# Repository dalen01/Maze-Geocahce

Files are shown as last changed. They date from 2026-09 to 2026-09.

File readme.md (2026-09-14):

# Maze Geocache

An electronic maze puzzle inspired by the maze module in *Keep Talking and Nobody Explodes*. A player uses an arcade joystick to move a white light through an invisible maze on a 6×6 RGB LED matrix. Reaching four randomly selected goals in succession triggers a solenoid and opens the geocache.

This repository contains the Arduino firmware, KiCad PCB design and production files, enclosure models, and laser-cutting drawings required to build the project.

## How it works

- The two green LEDs identify which of the nine maze layouts is active.
- The white LED is the player's current position.
- The red LED is the goal.
- The joystick moves the player up, down, left, or right.
- Hitting a wall or the edge of the matrix displays a red cross and resets progress.
- Reaching a goal displays the number of rounds remaining and loads a new random maze.
- Completing four mazes plays a victory animation and energizes the solenoid for 500 ms.

The walls are intentionally not shown on the LED matrix. Players must use an external maze reference or solve the layout by deduction.

## Hardware

The supplied PCB is designed around the following main components:

- Arduino Nano or a pin-compatible board
- 36 × WS2812B addressable RGB LEDs arranged as a 6×6 matrix
- Arcade joystick with four directional switches
- Solenoid lock
- TIP120 Darlington transistor and SS34 flyback diode for solenoid control
- 3 × AA battery holder
- Custom PCB and enclosure

See [`PCB Design/Maze Geocache/production/bom.csv`](PCB%20Design/Maze%20Geocache/production/bom.csv) for the PCB bill of materials and component footprints.

## Pin assignment

| Function | Arduino Nano pin |
| --- | ---: |
| Solenoid control | D2 |
| Joystick up | D3 |
| Joystick down | D4 |
| Joystick right | D5 |
| Joystick left | D6 |
| WS2812B data | D7 |

The directional inputs use the Arduino's internal pull-up resistors and are active low.

## Firmware setup

### Requirements

- Arduino IDE or Arduino CLI
- Arduino AVR Boards package
- [Adafruit NeoPixel](https://github.com/adafruit/Adafruit_NeoPixel) library

### Prepare the sketch

The current sketch contains an absolute Windows path for `MazeWalls.h`. Before compiling on another computer:

1. Copy `Code/MazeWalls.h` into `Code/Maze/`.
2. Change the second line of `Code/Maze/Maze.ino` to:

```cpp
#include "MazeWalls.h"
```

### Upload with Arduino IDE

1. Open `Code/Maze/Maze.ino`.
2. Install **Adafruit NeoPixel** from the Library Manager.
3. Select **Arduino Nano** and the correct processor variant and serial port.
4. Compile and upload the sketch.
5. Optionally open the Serial Monitor at **9600 baud** to view movement and game-state messages.

## Assembly notes

1. Manufacture and populate the PCB from the files in `PCB Design/Maze Geocache/`.
2. Connect the four joystick switches to the matching UP, DOWN, LEFT, and RIGHT JST connectors.
3. Connect the solenoid to the two-pin screw terminal.
4. Install the Arduino Nano with the correct orientation.
5. Fit the PCB, joystick, lock, and battery holder into the enclosure.
6. Test all controls and the lock release before closing the enclosure.

The solenoid is an inductive, relatively high-current load. Do not drive it directly from an Arduino pin. Confirm the solenoid voltage, polarity, current requirement, transistor pinout, flyback-diode orientation, and power-source capability before applying power.

## Repository layout

| Path | Contents |
| --- | --- |
| `Code/` | Arduino sketch and maze wall definitions |
| `PCB Design/` | KiCad schematics, PCB layout, 3D board model, BOM, placement data, and fabrication archive |
| `3D Files/` | Fusion 360 archive and STEP model of the complete enclosure |
| `DXF Files/` | Laser-cutting drawings for the box and acrylic window |

## Customization

- Change `numberToGo` in `Maze.ino` to alter the number of successful mazes required to unlock the cache.
- Adjust the RGB values in `drawGame()` to change marker colors or brightness.
- Edit `circlePos`, `wallsVertical`, and `wallsHorizontal` in `MazeWalls.h` to change or add maze layouts. Update `MAZE_COUNT` when adding or removing layouts.
- Change the 500 ms delay in the victory sequence if the lock needs a different activation time, while staying within the solenoid's safe duty cycle.

## Fabrication warning

Review the PCB, mechanical files, clearances, power design, and production outputs before ordering parts or manufacturing. The repository does not include a verified electrical rating for the solenoid or batteries, and the design files should not be treated as production-ready without an independent check.

## Acknowledgements

The puzzle concept is inspired by the maze module from *Keep Talking and Nobody Explodes*. This is an independent fan project and is not affiliated with or endorsed by Steel Crate Games.

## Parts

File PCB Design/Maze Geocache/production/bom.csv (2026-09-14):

Designator | Footprint | Quantity | Value | LCSC Part #
A1 | Arduino_Nano | 1 | Arduino_Nano_v2.x
BT1 | BatteryHolder_TruPower_BH-331P_3xAA | 1 | Battery
C1, C10, C11, C12, C13, C14, C15, C16, C17, C18, C19, C2, C20, C21, C22, C23, C24, C25, C26, C27, C28, C29, C3, C30, C31, C32, C33, C34, C35, C36, C4, C5, C6, C7, C8, C9 | 1206 | 36 | 10pF
D1 | SS34 | 1 | SS34
D10, D11, D12, D13, D14, D15, D16, D17, D18, D19, D2, D20, D21, D22, D23, D24, D25, D26, D27, D28, D29, D3, D30, D31, D32, D33, D34, D35, D36, D37, D4, D5, D6, D7, D8, D9 | LED_WS2812B_PLCC4_5.0x5.0mm_P3.2mm | 36 | WS2812B
H1, H2, H3, H4 | MountingHole_2.5mm_Pad | 4 | MountingHole_Pad
J1 | JST_PH_B3B-PH-K_1x03_P2.00mm_Vertical | 1 | Joystick connector UP
J2 | JST_PH_B3B-PH-K_1x03_P2.00mm_Vertical | 1 | Joystick connector DOWN
J3 | JST_PH_B3B-PH-K_1x03_P2.00mm_Vertical | 1 | Joystick connector RIGHT
J4 | JST_PH_B3B-PH-K_1x03_P2.00mm_Vertical | 1 | Joystick connector LEFT
J5 | Altech_AK300_1x02_P5.00mm_45-Degree | 1 | Solenoid
Q1 | TO-220-3_Vertical | 1 | TIP120
R1 | 1206 | 1 | 220

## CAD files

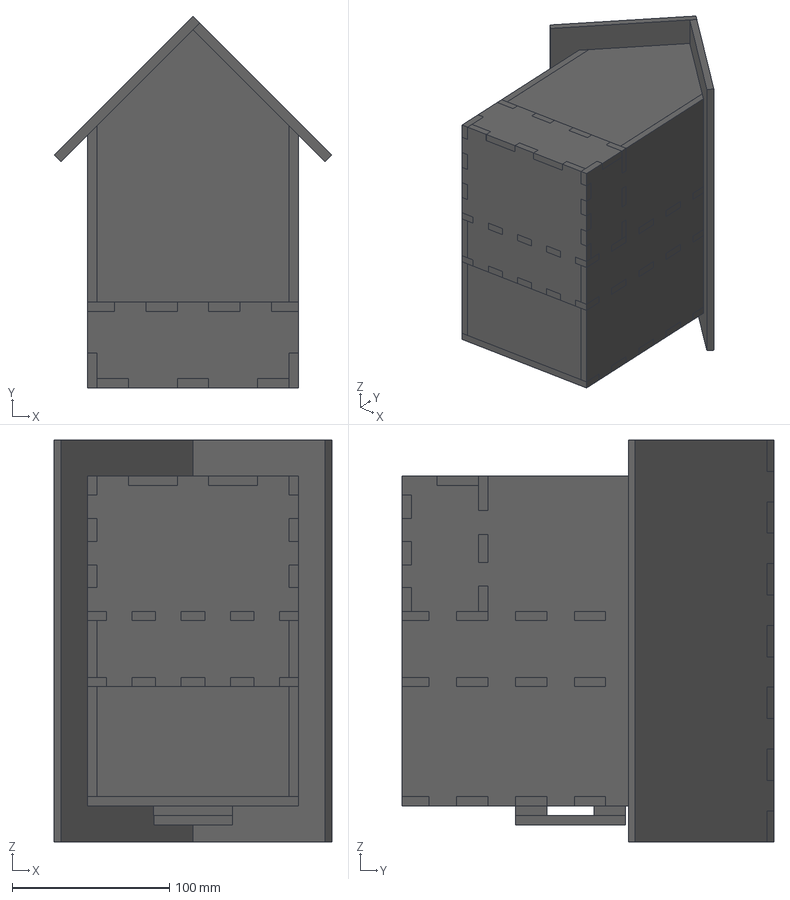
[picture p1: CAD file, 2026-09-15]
3D Files/Complete box with content 6mm.step
176.7 x 236.5 x 255.8 mm

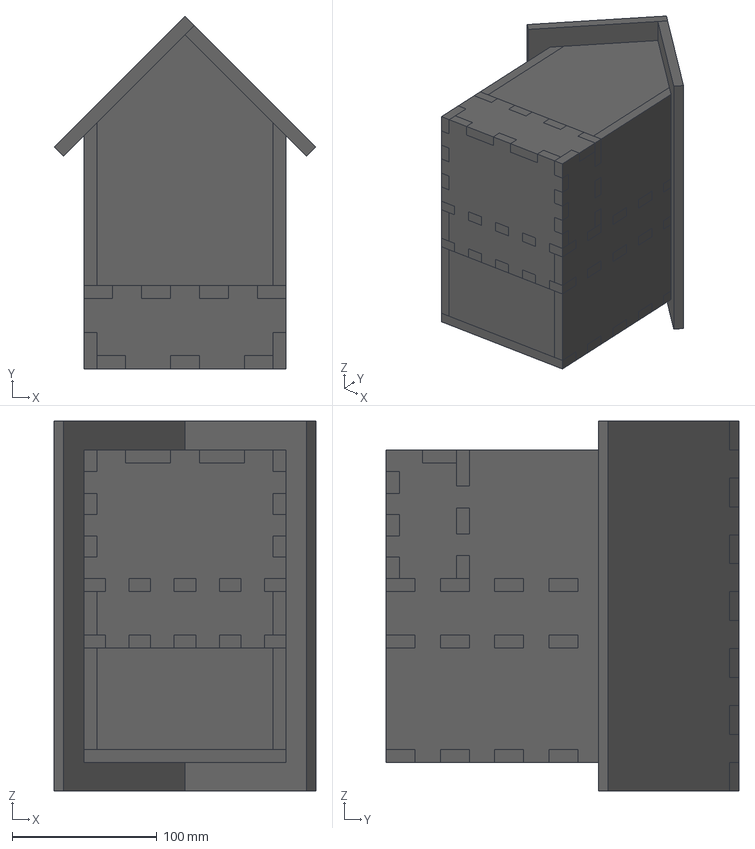
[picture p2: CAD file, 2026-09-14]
3D Files/Maze complete box with content.step
180.9 x 243.7 x 255.8 mm

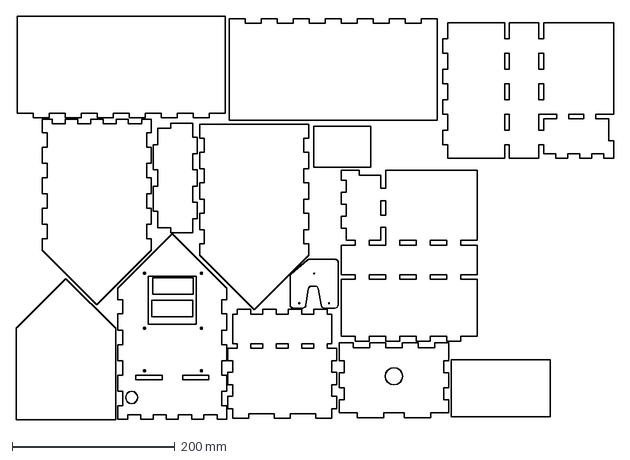
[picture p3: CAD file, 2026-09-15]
DXF Files/Box complete 6mm.dxf
733.9 x 495.8 mm

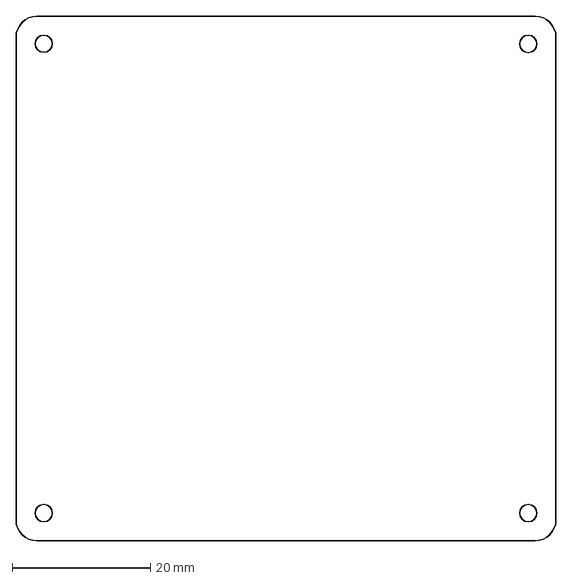
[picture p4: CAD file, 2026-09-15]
DXF Files/Acrylic 6mm.dxf
78.0 x 75.8 mm

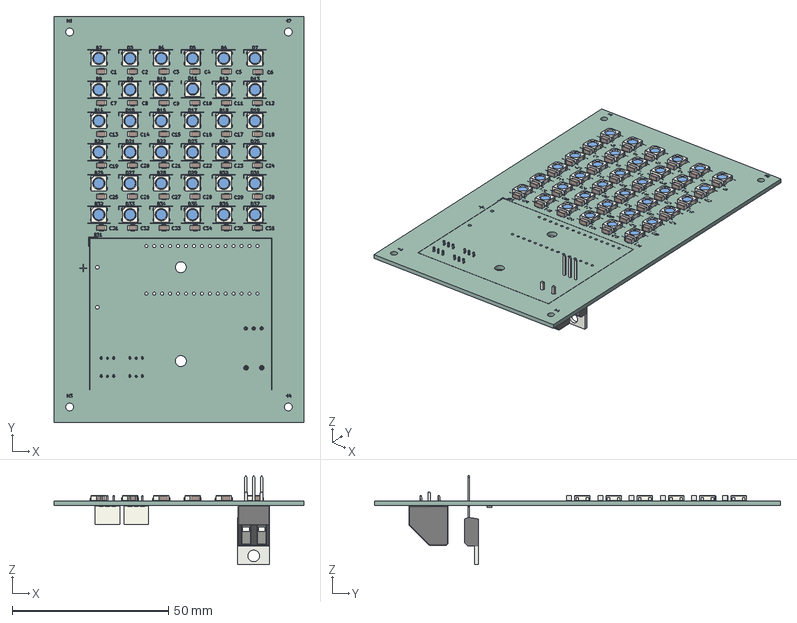
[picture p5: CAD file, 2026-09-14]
PCB Design/Maze Geocache/Maze Geocache.step
80.0 x 130.0 x 28.5 mm
C_1206_3216Metric x 36
LED_WS2812B_PLCC4_50x50mm_P32mm x 36
JST_B3B_PH_K x 4
R_1206_3216Metric
TO-220-3_Vertical
AK300_2
MasFFF3_silkscreen x 2
MasFFF3_PCB

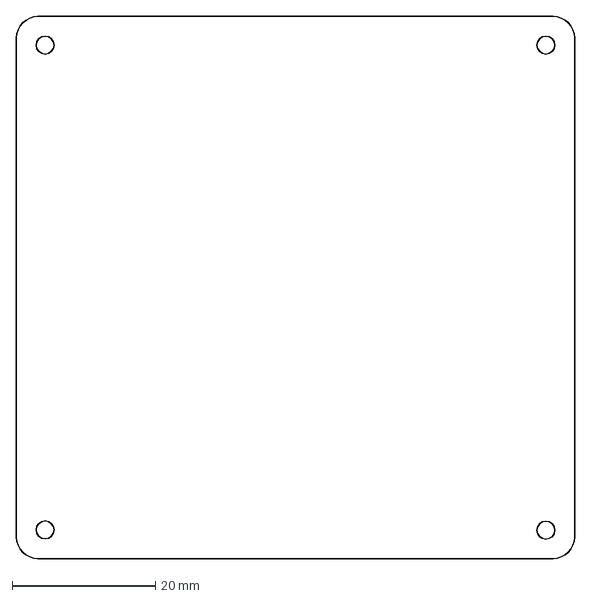
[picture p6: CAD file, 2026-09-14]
DXF Files/Acryl glass.dxf
78.0 x 75.8 mm

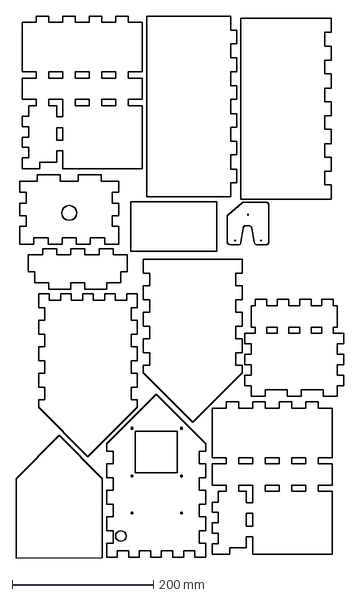
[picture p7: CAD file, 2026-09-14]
DXF Files/Box ready.dxf
463.5 x 767.5 mm

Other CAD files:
3D Files/Maze Geocache Fusion Archive 6mm.f3d
3D Files/Maze Geocache Fusion Archive.f3d

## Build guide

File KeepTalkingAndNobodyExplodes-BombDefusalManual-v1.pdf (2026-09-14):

8/28/2020 | KeepTalkingandNobodyExplodes-BombDefusalManual-en-v1

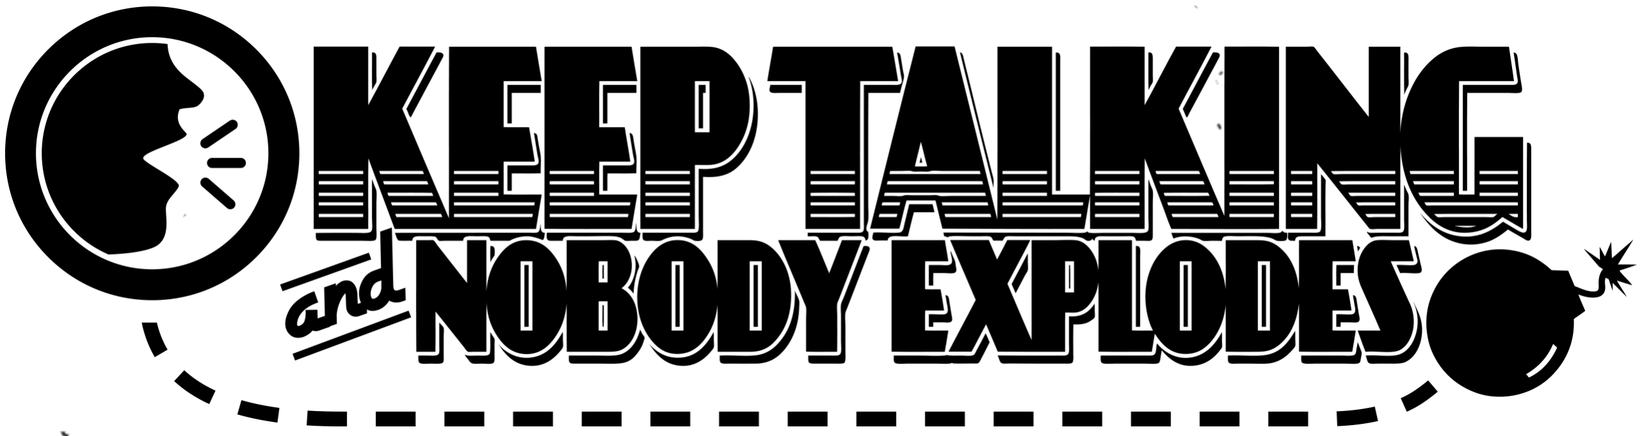
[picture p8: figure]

file:///C:/SteelCrate/KTaNE/git/Manual/build/en/print/source_html/index.html | 1/23

# BOMB DEFUSAL MANUAL

# www.keeptalkinggame.com

# Version 1 Verification Code: 241

Video game companion manual. Find out more at www.keeptalkinggame.com

file:///C:/SteelCrate/KTaNE/git/Manual/build/en/print/source_html/index.html | 2/23

Welcome to the dangerous and challenging world of bomb defusing.

Study this manual carefully; you are the expert. In these pages you will find everything you need to know to defuse even the most insidious of bombs. And remember — One small oversight and it could all be over!

Keep Talking and Nobody Explodes v. 1 | Introduction

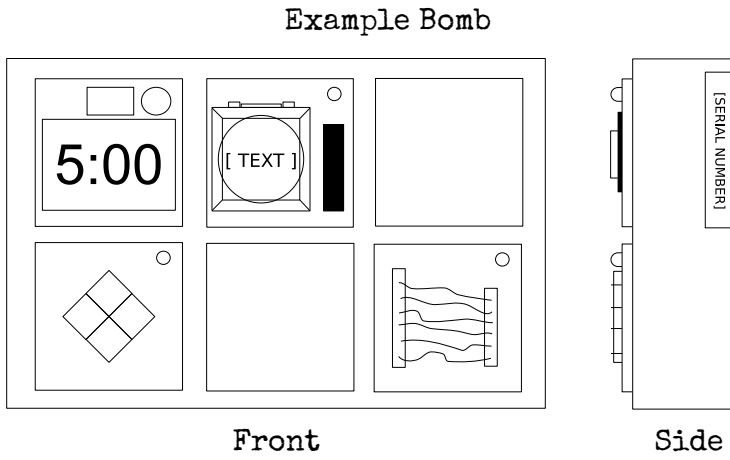
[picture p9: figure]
Example Bomb; Front; Side

file:///C:/SteelCrate/KTaNE/git/Manual/build/en/print/source_html/index.html | 3/23

Strike
Indicator

# Defusing Bombs

A bomb will explode when its countdown timer reaches 0:00 or when too many strikes have been recorded. The only way to defuse a bomb is to disarm all of its modules before its countdown timer expires.

Modules

Each bomb will include up to 11 modules that must be disarmed. Each module is discrete and can be disarmed in any order.

Instructions for disarming modules can be found in Section 1. "Needy" modules present a special case and are described in Section 2.

Strikes

When the Defuser makes a mistake, the bomb will record a strike which will be displayed on the indicator above the countdown timer. Bombs with a strike indicator will explode upon the third strike. The timer will begin to count down faster after a strike has been recorded.

If no strike indicator is present above the countdown timer, the bomb will explode upon the first strike, leaving no room for error.

Gathering Information

Some disarming instructions will require specific information about the bomb, such as the serial number. This type of information can typically be found on the top, bottom, or sides of the bomb casing. See Appendix A, B, and C for identification instructions that will be useful in disarming certain modules.

Keep Talking and Nobody Explodes v. 1 | Defusing Bombs

file:///C:/SteelCrate/KTaNE/git/Manual/build/en/print/source_html/index.html | 4/23

# Section 1: Modules

Modules can be identified by an LED in the top right corner. When this LED is lit green, the module has been disarmed.

All modules must be disarmed to defuse the bomb.

Keep Talking and Nobody Explodes v. 1 | Section 1: Modules

file:///C:/SteelCrate/KTaNE/git/Manual/build/en/print/source_html/index.html | 5/23

## On the Subject of Wires

Wires are the lifeblood of electronics! Wait, no, electricity is the lifeblood. Wires are more like the arteries. The veins? No matter…

A wire module can have 3-6 wires on it.
Only the one correct wire needs to be cut to disarm the module.
Wire ordering begins with the first on the top.

3 wires:
If there are no red wires, cut the second wire.
Otherwise, if the last wire is white, cut the last wire.
Otherwise, if there is more than one blue wire, cut the last blue wire. Otherwise, cut the last wire.

4 wires:
If there is more than one red wire and the last digit of the serial number is odd, cut the last red wire.
Otherwise, if the last wire is yellow and there are no red wires, cut the first wire.
Otherwise, if there is exactly one blue wire, cut the first wire.
Otherwise, if there is more than one yellow wire, cut the last wire. Otherwise, cut the second wire.

5 wires:
If the last wire is black and the last digit of the serial number is odd, cut the fourth wire.
Otherwise, if there is exactly one red wire and there is more than one yellow wire, cut the first wire.
Otherwise, if there are no black wires, cut the second wire.
Otherwise, cut the first wire.

6 wires:
If there are no yellow wires and the last digit of the serial number is odd, cut the third wire.
Otherwise, if there is exactly one yellow wire and there is more than one white wire, cut the fourth wire.
Otherwise, if there are no red wires, cut the last wire.
Otherwise, cut the fourth wire.
Keep Talking and Nobody Explodes v. 1 | Wires

file:///C:/SteelCrate/KTaNE/git/Manual/build/en/print/source_html/index.html | 6/23

## On the Subject of The Button

You might think that a button telling you to press it is pretty straightforward. That’s the kind of thinking that gets people exploded.

See Appendix A for indicator identification reference. See Appendix B for battery identification reference.

Follow these rules in the order they are listed. Perform the
first action that applies:
1. If the button is blue and the button says "Abort", hold the button and refer to "Releasing a Held Button".
2. If there is more than 1 battery on the bomb and the button says "Detonate", press and immediately release the button.
3. If the button is white and there is a lit indicator with label CAR, hold the button and refer to "Releasing a Held Button".
4. If there are more than 2 batteries on the bomb and there is a lit indicator with label FRK, press and immediately release the button.
5. If the button is yellow, hold the button and refer to "Releasing a Held Button".
6. If the button is red and the button says "Hold", press and immediately release the button.
7. If none of the above apply, hold the button and refer to "Releasing a Held Button".

Releasing a Held Button

If you start holding the button down, a colored strip will light up on the right side of the module. Based on its color, you must release the button at a specific point in time:

Blue strip: release when the countdown timer has a 4 in any position. White strip: release when the countdown timer has a 1 in any position. Yellow strip: release when the countdown timer has a 5 in any position. Any other color strip: release when the countdown timer has a 1 in any position.

Keep Talking and Nobody Explodes v. 1 | The Button

file:///C:/SteelCrate/KTaNE/git/Manual/build/en/print/source_html/index.html | 7/23

## On the Subject of Keypads

I'm not sure what these symbols are, but I suspect they have something to do with occult.

Only one column below has all four of the symbols from the keypad.
Press the four buttons in the order their symbols appear from top to bottom within that column.
Keep Talking and Nobody Explodes v. 1 | Keypads

file:///C:/SteelCrate/KTaNE/git/Manual/build/en/print/source_html/index.html | 8/23

## On the Subject of Simon Says

This is like one of those toys you played with as a kid where you have to match the pattern that appears, except this one is a knockoff that was probably purchased at a dollar store.

1. One of the four colored buttons will flash.
2. Using the correct table below, press the button with the
corresponding color.
3. The original button will flash, followed by another. Repeat this sequence in order using the color mapping.
4. The sequence will lengthen by one each time you correctly enter a sequence until the module is disarmed.

## Blue

Red | Yellow

## Green

If the serial number contains a vowel:

Red Flash | Blue Flash | Green Flash | Yellow Flash
Button to press: | No Strikes | Blue | Red | Yellow | Green
| 1 Strike | Yellow | Green | Blue | Red
| 2 Strikes | Green | Red | Yellow | Blue

If the serial number does not contain a vowel:

Red Flash | Blue Flash | Green Flash | Yellow Flash
Button to press: | No Strikes | Blue | Yellow | Green | Red
| 1 Strike | Red | Blue | Yellow | Green
| 2 Strikes | Yellow | Green | Blue | Red
Keep Talking and Nobody Explodes v. 1 | Simon Says

file:///C:/SteelCrate/KTaNE/git/Manual/build/en/print/source_html/index.html | 9/23

## On the Subject of Who’s on First

This contraption is like something out of a sketch comedy routine, which might be funny if it wasn't connected to a bomb. I’ll keep this brief, as words only complicate matters.

1. Read the display and use step 1 to determine which button label to read.
2. Using this button label, use step 2 determine which button to push.
3. Repeat until the module has been disarmed.
Step 1:

Based on the display, read the label of a particular button and proceed to step 2:

YES | FIRST | DISPLAY | OKAY | SAYS | NOTHING
BLANK | NO | LED | LEAD | READ
RED | REED | LEED | HOLD ON | YOU | YOU ARE
YOUR | YOU'RE | UR | THERE | THEY'RE | THEIR
THEY ARE | SEE | C | CEE
Keep Talking and Nobody Explodes v. 1 | Who's on First

file:///C:/SteelCrate/KTaNE/git/Manual/build/en/print/source_html/index.html | 10/23
Step 2:

Using the label from step 1, push the first button that appears in its corresponding list:

"READY": | YES, OKAY, WHAT, MIDDLE, LEFT, PRESS, RIGHT, BLANK, READY, NO, FIRST, UHHH, NOTHING, WAIT
"FIRST": | LEFT, OKAY, YES, MIDDLE, NO, RIGHT, NOTHING, UHHH, WAIT, READY, BLANK, WHAT, PRESS, FIRST
"NO": | BLANK, UHHH, WAIT, FIRST, WHAT, READY, RIGHT, YES, NOTHING, LEFT, PRESS, OKAY, NO, MIDDLE
"BLANK": | WAIT, RIGHT, OKAY, MIDDLE, BLANK, PRESS, READY, NOTHING, NO, WHAT, LEFT, UHHH, YES, FIRST
"NOTHING": | UHHH, RIGHT, OKAY, MIDDLE, YES, BLANK, NO, PRESS, LEFT, WHAT, WAIT, FIRST, NOTHING, READY
"YES": | OKAY, RIGHT, UHHH, MIDDLE, FIRST, WHAT, PRESS, READY, NOTHING, YES, LEFT, BLANK, NO, WAIT
"WHAT": | UHHH, WHAT, LEFT, NOTHING, READY, BLANK, MIDDLE, NO, OKAY, FIRST, WAIT, YES, PRESS, RIGHT
"UHHH": | READY, NOTHING, LEFT, WHAT, OKAY, YES, RIGHT, NO, PRESS, BLANK, UHHH, MIDDLE, WAIT, FIRST
"LEFT": | RIGHT, LEFT, FIRST, NO, MIDDLE, YES, BLANK, WHAT, UHHH, WAIT, PRESS, READY, OKAY, NOTHING
"RIGHT": | YES, NOTHING, READY, PRESS, NO, WAIT, WHAT, RIGHT, MIDDLE, LEFT, UHHH, BLANK, OKAY, FIRST
"MIDDLE": | BLANK, READY, OKAY, WHAT, NOTHING, PRESS, NO, WAIT, LEFT, MIDDLE, RIGHT, FIRST, UHHH, YES
"OKAY": | MIDDLE, NO, FIRST, YES, UHHH, NOTHING, WAIT, OKAY, LEFT, READY, BLANK, PRESS, WHAT, RIGHT
"WAIT": | UHHH, NO, BLANK, OKAY, YES, LEFT, FIRST, PRESS, WHAT, WAIT, NOTHING, READY, RIGHT, MIDDLE
"PRESS": | RIGHT, MIDDLE, YES, READY, PRESS, OKAY, NOTHING, UHHH, BLANK, LEFT, FIRST, WHAT, NO, WAIT
"YOU": | SURE, YOU ARE, YOUR, YOU'RE, NEXT, UH HUH, UR, HOLD, WHAT?, YOU, UH UH, LIKE, DONE, U
"YOU ARE": | YOUR, NEXT, LIKE, UH HUH, WHAT?, DONE, UH UH, HOLD, YOU, U, YOU'RE, SURE, UR, YOU ARE
"YOUR": | UH UH, YOU ARE, UH HUH, YOUR, NEXT, UR, SURE, U, YOU'RE, YOU, WHAT?, HOLD, LIKE, DONE
"YOU'RE": | YOU, YOU'RE, UR, NEXT, UH UH, YOU ARE, U, YOUR, WHAT?, UH HUH, SURE, DONE, LIKE, HOLD
"UR": | DONE, U, UR, UH HUH, WHAT?, SURE, YOUR, HOLD, YOU'RE, LIKE, NEXT, UH UH, YOU ARE, YOU
"U": | UH HUH, SURE, NEXT, WHAT?, YOU'RE, UR, UH UH, DONE, U, YOU, LIKE, HOLD, YOU ARE, YOUR
"UH HUH": | UH HUH, YOUR, YOU ARE, YOU, DONE, HOLD, UH UH, NEXT, SURE, LIKE, YOU'RE, UR, U, WHAT?
"UH UH": | UR, U, YOU ARE, YOU'RE, NEXT, UH UH, DONE, YOU, UH HUH, LIKE, YOUR, SURE, HOLD, WHAT?
"WHAT?": | YOU, HOLD, YOU'RE, YOUR, U, DONE, UH UH, LIKE, YOU ARE, UH HUH, UR, NEXT, WHAT?, SURE
"DONE": | SURE, UH HUH, NEXT, WHAT?, YOUR, UR, YOU'RE, HOLD, LIKE, YOU, U, YOU ARE, UH UH, DONE
"NEXT": | WHAT?, UH HUH, UH UH, YOUR, HOLD, SURE, NEXT, LIKE, DONE, YOU ARE, UR, YOU'RE, U, YOU
"HOLD": | YOU ARE, U, DONE, UH UH, YOU, UR, SURE, WHAT?, YOU'RE, NEXT, HOLD, UH HUH, YOUR, LIKE
"SURE": | YOU ARE, DONE, LIKE, YOU'RE, YOU, HOLD, UH HUH, UR, SURE, U, WHAT?, NEXT, YOUR, UH UH
"LIKE": | YOU'RE, NEXT, U, UR, HOLD, DONE, UH UH, WHAT?, UH HUH, YOU, LIKE, SURE, YOU ARE, YOUR
Keep Talking and Nobody Explodes v. 1 | Who's on First

file:///C:/SteelCrate/KTaNE/git/Manual/build/en/print/source_html/index.html | 11/23

## On the Subject of Memory

Memory is a fragile thing but so is everything else when a bomb goes off, so pay attention!

Press the correct button to progress the module to the next stage. Complete all stages to disarm the module. Pressing an incorrect button will reset the module back to stage 1.
Button positions are ordered from left to right.

Stage 1:
If the display is 1, press the button in the second position. If the display is 2, press the button in the second position. If the display is 3, press the button in the third position. If the display is 4, press the button in the fourth position.

Stage 2:
If the display is 1, press the button labeled "4".
If the display is 2, press the button in the same position as you pressed in stage 1. If the display is 3, press the button in the first position.
If the display is 4, press the button in the same position as you pressed in stage 1.

Stage 3:
If the display is 1, press the button with the same label you pressed in stage 2.
If the display is 2, press the button with the same label you pressed in stage 1. If the display is 3, press the button in the third position.
If the display is 4, press the button labeled "4".

Stage 4:
If the display is 1, press the button in the same position as you pressed in stage 1. If the display is 2, press the button in the first position.
If the display is 3, press the button in the same position as you pressed in stage 2. If the display is 4, press the button in the same position as you pressed in stage 2.

Stage 5:
If the display is 1, press the button with the same label you pressed in stage 1.
If the display is 2, press the button with the same label you pressed in stage 2. If the display is 3, press the button with the same label you pressed in stage 4. If the display is 4, press the button with the same label you pressed in stage 3.
Keep Talking and Nobody Explodes v. 1 | Memory

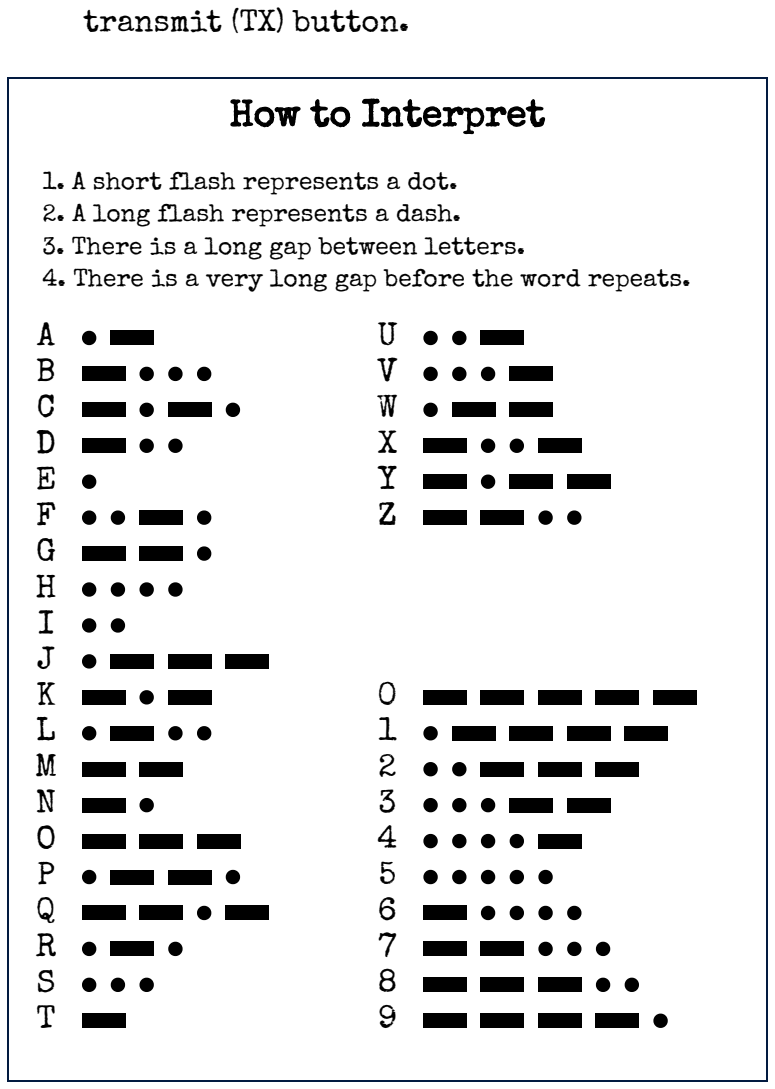
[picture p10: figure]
How to Interpret; 1. A short flash represents a dot. 2. A long flash represents a dash. 3. There is a long gap between letters.; transmit (TX) button.

file:///C:/SteelCrate/KTaNE/git/Manual/build/en/print/source_html/index.html | 12/23
4. There is a very long gap before the word repeats.

## On the Subject of Morse Code

An antiquated form of naval communication? What next? At least it's genuine Morse Code, so pay attention and you might just learn something.

Interpret the signal from the flashing light using the Morse Code chart to spell one of the words in the table.
The signal will loop, with a long gap between
repetitions.
Once the word is identified, set the corresponding frequency and press the
If the word is: | Respond at frequency:
shell | 3.505 MHz
halls | 3.515 MHz
slick | 3.522 MHz
trick | 3.532 MHz
boxes | 3.535 MHz
leaks | 3.542 MHz
strobe | 3.545 MHz
bistro | 3.552 MHz
flick | 3.555 MHz
bombs | 3.565 MHz
break | 3.572 MHz
brick | 3.575 MHz
steak | 3.582 MHz
sting | 3.592 MHz
vector | 3.595 MHz
beats | 3.600 MHz
Keep Talking and Nobody Explodes v. 1 | Morse Code

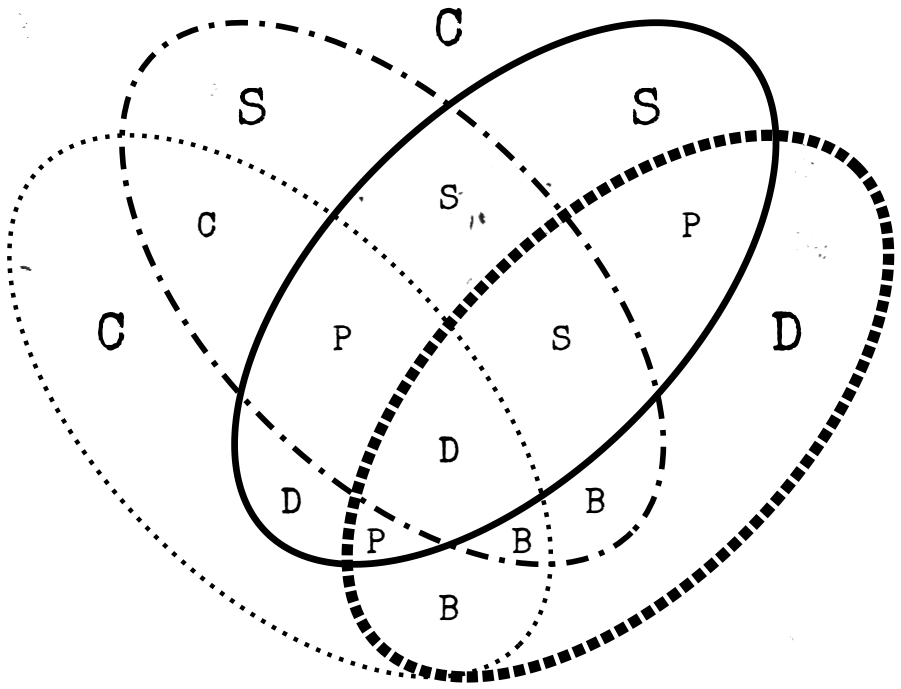
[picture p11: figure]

file:///C:/SteelCrate/KTaNE/git/Manual/build/en/print/source_html/index.html | 13/23

## On the Subject of Complicated Wires

These wires aren't like the others. Some have stripes! That makes them completely different. The good news is that we've found a concise set of instructions on what to do about it! Maybe too concise...

Look at each wire: there is an LED above the wire and a space for a "★" symbol below the wire.
For each wire/LED/symbol combination, use the Venn diagram below to decide whether or not to cut the wire. Each wire may be striped with multiple colors.
Keep Talking and Nobody Explodes v. 1 | Complicated Wires

Wire has red
coloring

Wire has blue
coloring

Has ★ symbol

LED is on

Letter | Instruction
C | Cut the wire
D | Do not cut the wire
S | Cut the wire if the last digit of the serial number is even
P | Cut the wire if the bomb has a parallel port
B | Cut the wire if the bomb has two or more batteries

See Appendix B for battery identification reference. See Appendix C for port identification reference.

file:///C:/SteelCrate/KTaNE/git/Manual/build/en/print/source_html/index.html | 14/23

## On the Subject of Wire Sequences

It's hard to say how this mechanism works. The engineering is pretty impressive, but there must have been an easier way to manage nine wires.

Within this module there are several panels with wires on them, but only one panel is visible at a time. Switch
to the next panel by using the down button and the
previous panel by using the up button.
Do not switch to the next panel until you are sure that you have cut all necessary wires on the current panel.
Cut the wires as directed by the following table. Wire occurrences are cumulative over all panels within the module.
Red Wire Occurrences | Blue Wire Occurrences | Black Wire Occurrences
Wire Occurrence | Cut if connected to: | Wire Occurrence | Cut if connected to: | Wire Occurrence | Cut if connected to:
First red occurrence | C | First blue occurrence | B | First black occurrence | A, B or C
Second red occurrence | B | Second blue occurrence | A or C | Second black occurrence | A or C
Third red occurrence | A | Third blue occurrence | B | Third black occurrence | B
Fourth red occurrence | A or C | Fourth blue occurrence | A | Fourth black occurrence | A or C
Fifth red occurrence | B | Fifth blue occurrence | B | Fifth black occurrence | B
Sixth red occurrence | A or C | Sixth blue occurrence | B or C | Sixth black occurrence | B or C
Seventh red occurrence | A, B or C | Seventh blue occurrence | C | Seventh black occurrence | A or B
Eighth red occurrence | A or B | Eighth blue occurrence | A or C | Eighth black occurrence | C
Ninth red occurrence | B | Ninth blue occurrence | A | Ninth black occurrence | C
Keep Talking and Nobody Explodes v. 1 | Wire Sequences

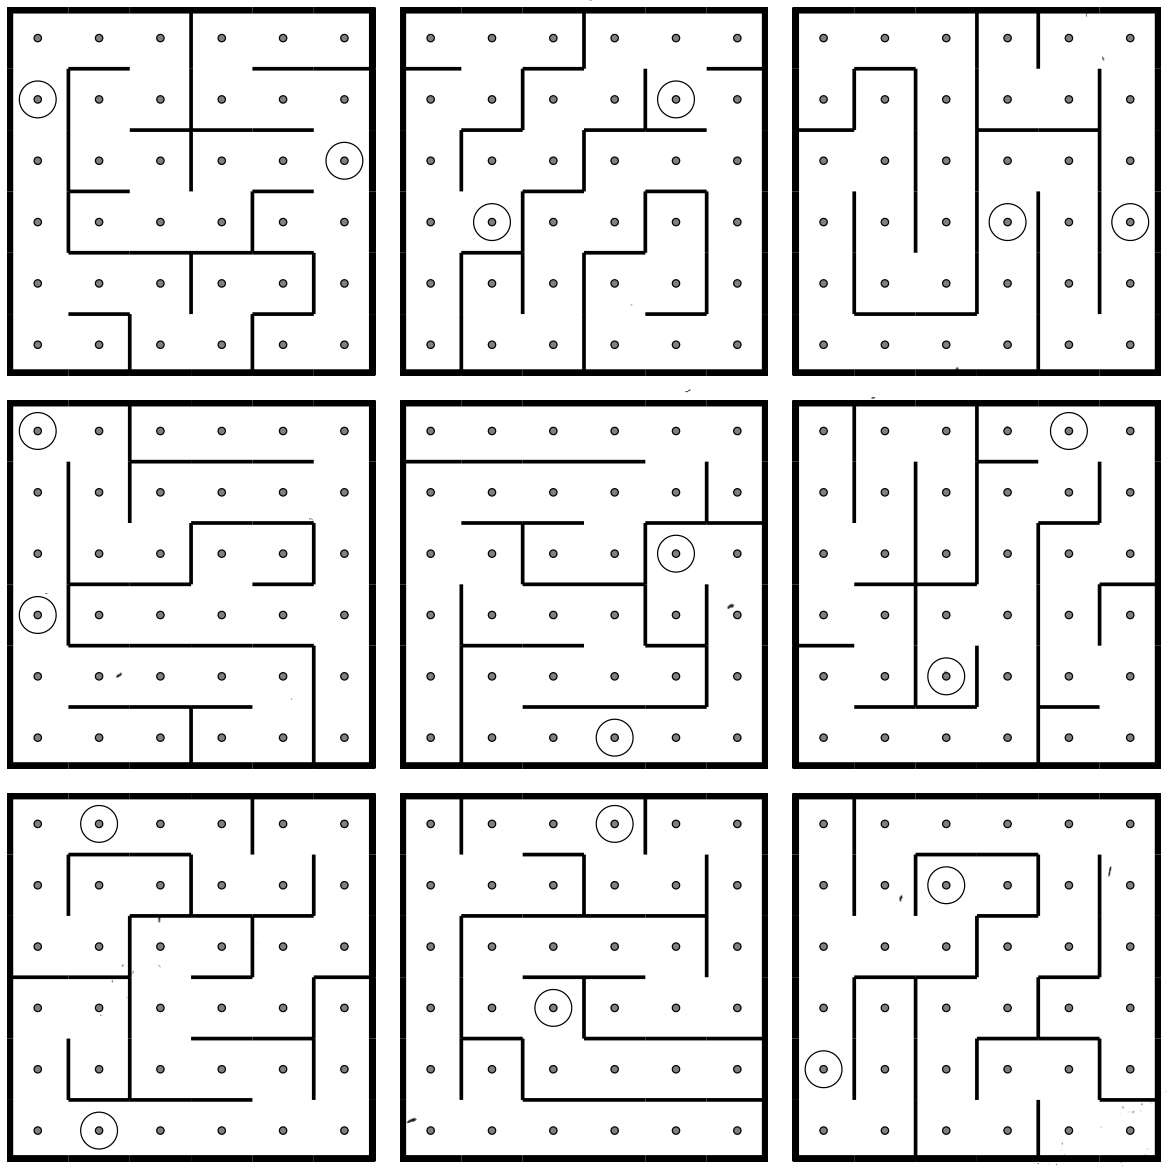
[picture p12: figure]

file:///C:/SteelCrate/KTaNE/git/Manual/build/en/print/source_html/index.html | 15/23

## On the Subject of Mazes

This seems to be some kind of maze, probably stolen off of a restaurant placemat.

Find the maze with matching circular markings.
The defuser must navigate the white light to the red triangle using the arrow buttons.
Warning: Do not cross the lines shown in the maze. These lines are invisible on the bomb.
Keep Talking and Nobody Explodes v. 1 | Mazes

file:///C:/SteelCrate/KTaNE/git/Manual/build/en/print/source_html/index.html | 16/23

## On the Subject of Passwords

Fortunately this password doesn't seem to meet standard government security requirements: 22 characters, mixed case, numbers in random order without any palindromes above length 3.

The buttons above and below each letter will cycle through the possibilities for that position.
Only one combination of the available letters will
match a password below.
Press the submit button once the correct word has been set.
about | after | again | below | could
every | first | found | great | house
large | learn | never | other | place
plant | point | right | small | sound
spell | still | study | their | there
these | thing | think | three | water
where | which | world | would | write
Keep Talking and Nobody Explodes v. 1 | Passwords

file:///C:/SteelCrate/KTaNE/git/Manual/build/en/print/source_html/index.html | 17/23

# Section 2: Needy Modules

Needy modules cannot be disarmed, but pose a recurrent hazard.

Needy modules can be identified as a module with a small 2‑digit timer in the top center. Interacting with the bomb may cause them to become activated. Once activated, these needy modules must be tended to regularly before their timer expires in order to prevent a strike.

Stay observant: needy modules may reactivate at any time.

Keep Talking and Nobody Explodes v. 1 | Section 2: Needy Modules

file:///C:/SteelCrate/KTaNE/git/Manual/build/en/print/source_html/index.html | 18/23

## On the Subject of Venting Gas

Computer hacking is hard work! Well, it usually is. This job could probably be performed by a simple drinking bird pressing the same key over and over again.

Respond to the computer prompts by pressing "Y" for "Yes" or "N" for "No".

Keep Talking and Nobody Explodes v. 1 | Venting Gas

file:///C:/SteelCrate/KTaNE/git/Manual/build/en/print/source_html/index.html | 19/23

## On the Subject of Capacitor Discharge

I'm going to guess that this is just meant to occupy your attention, because otherwise this is some shoddy electronics work.

Discharge the capacitor before it overloads by holding down the lever.

Keep Talking and Nobody Explodes v. 1 | Capacitor Discharge

file:///C:/SteelCrate/KTaNE/git/Manual/build/en/print/source_html/index.html | 20/23

## On the Subject of Knobs

Needlessly complicated and endlessly needy. Imagine if such expertise were used to make something other than diabolical puzzles.

The knob can be turned to one of four different positions.
The knob must be in the correct position when this
module's timer hits zero.
The correct position can be determined by the on/off configuration of the twelve LEDs.
Knob positions are relative to the "UP" label, which may have rotated.

LED Configurations

Up Position:
X | X | X
X | X | X | X | X
X | X | X
X | X | X | X

Down Position:
X | X | X
X | X | X | X | X
X | X | X
X | X

Left Position:
X
X | X | X | X

X

X X

Right Position:
X | X | X | X | X
X | X | X | X
X | X | X
X | X | X | X

X = Lit LED

Keep Talking and Nobody Explodes v. 1 | Knobs

## Appendix A: Indicator Identification Reference

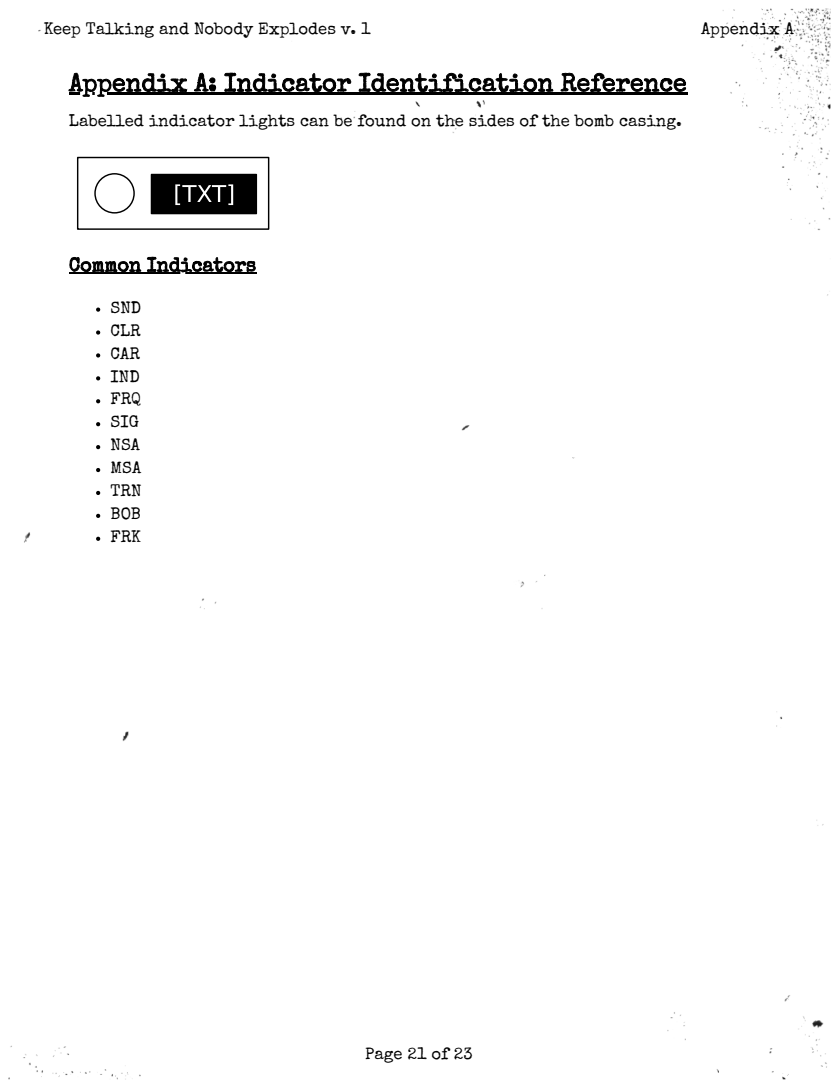
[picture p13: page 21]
file:///C:/SteelCrate/KTaNE/git/Manual/build/en/print/source_html/index.html; Common Indicators; SND CLR CAR IND FRQ SIG NSA MSA TRN BOB FRK; Keep Talking and Nobody Explodes v. 1; Appendix A

Labelled indicator lights can be found on the sides of the bomb casing.

file:///C:/SteelCrate/KTaNE/git/Manual/build/en/print/source_html/index.html | 22/23

## Appendix B: Battery Identification Reference

Common battery types can be found within enclosures on the sides of the bomb casing.

Battery | Type
| AA
| D
Keep Talking and Nobody Explodes v. 1 | Appendix B

## Appendix C: Port Identification Reference

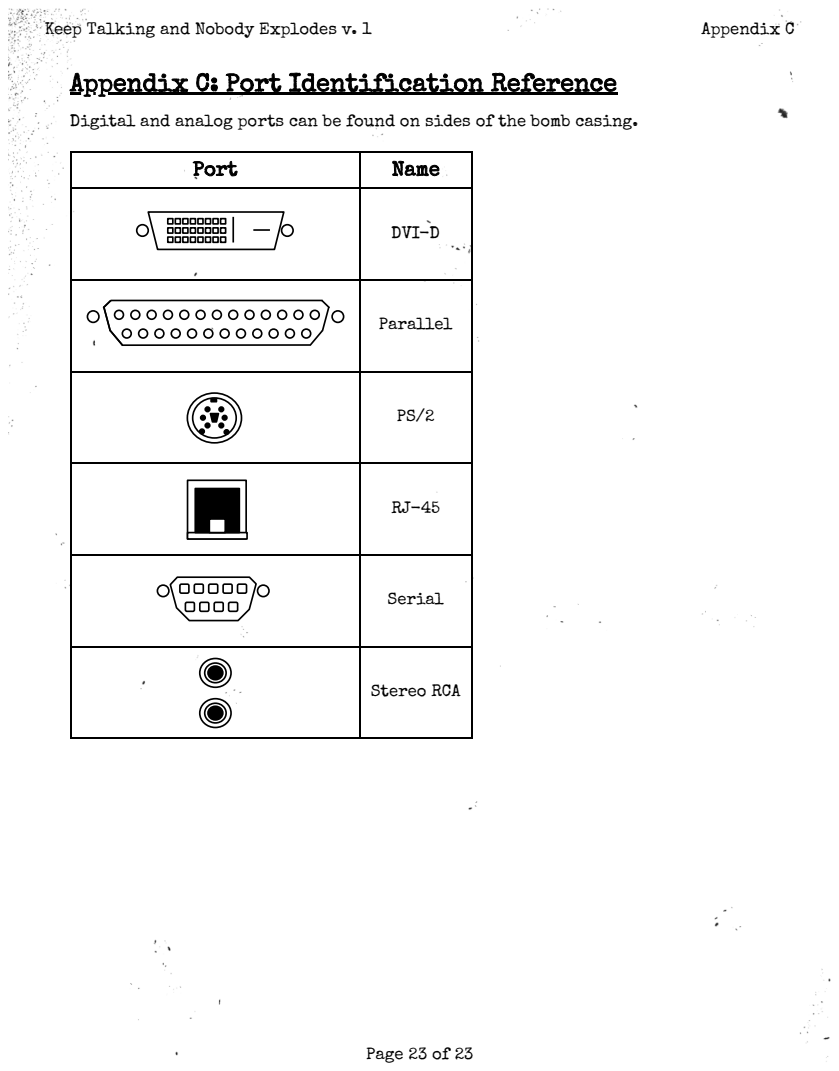
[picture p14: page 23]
file:///C:/SteelCrate/KTaNE/git/Manual/build/en/print/source_html/index.html; Keep Talking and Nobody Explodes v. 1; Appendix C

Digital and analog ports can be found on sides of the bomb casing.

Port | Name

DVI-D

Parallel

Serial

Stereo RCA

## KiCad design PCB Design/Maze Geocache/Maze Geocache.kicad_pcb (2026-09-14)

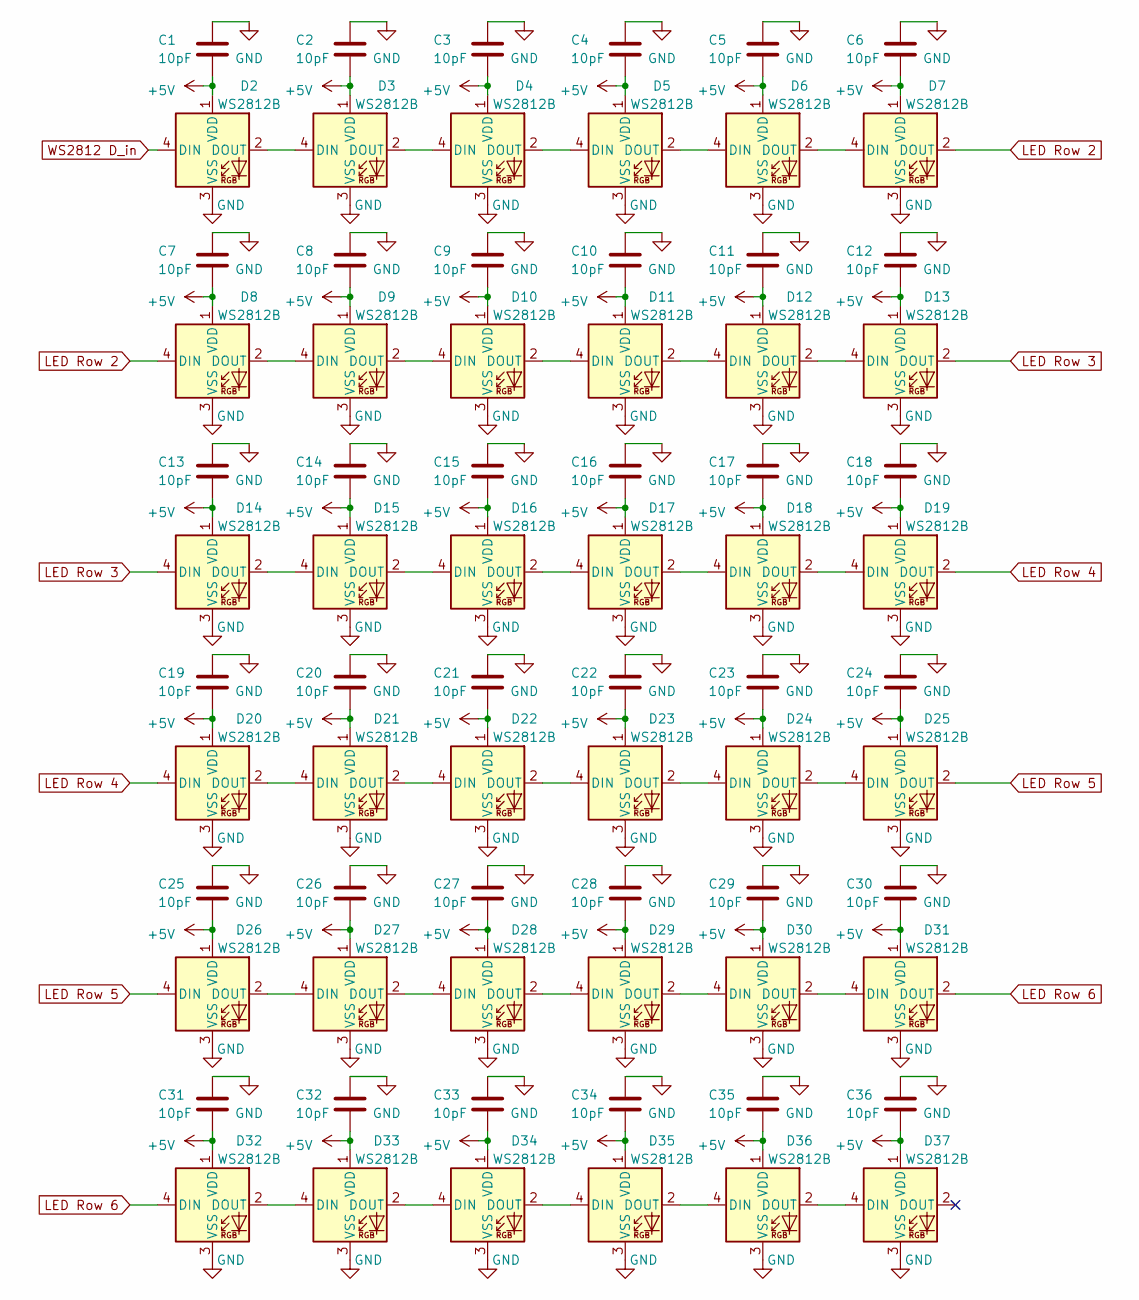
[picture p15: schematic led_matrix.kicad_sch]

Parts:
C1, C2, C3, C4, C5, C6, C7, C8, C9, C10, C11, C12, C13, C14, C15, C16, C17, C18, C19, C20, C21, C22, C23, C24, C25, C26, C27, C28, C29, C30, C31, C32, C33, C34, C35, C36: 10pF; C_1206_3216Metric_Pad1.33x1.80mm_HandSolder
D2, D3, D4, D5, D6, D7, D8, D9, D10, D11, D12, D13, D14, D15, D16, D17, D18, D19, D20, D21, D22, D23, D24, D25, D26, D27, D28, D29, D30, D31, D32, D33, D34, D35, D36, D37: WS2812B; LED_WS2812B_PLCC4_5.0x5.0mm_P3.2mm

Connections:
+5V: C1.2, C2.2, C3.2, C4.2, C5.2, C6.2, C7.2, C8.2, C9.2, C10.2, C11.2, C12.2, C13.2, C14.2, C15.2, C16.2, C17.2, C18.2, C19.2, C20.2, C21.2, C22.2, C23.2, C24.2, C25.2, C26.2, C27.2, C28.2, C29.2, C30.2, C31.2, C32.2, C33.2, C34.2, C35.2, C36.2, D2.1 (VDD), D3.1 (VDD), D4.1 (VDD), D5.1 (VDD), D6.1 (VDD), D7.1 (VDD), D8.1 (VDD), D9.1 (VDD), D10.1 (VDD), D11.1 (VDD), D12.1 (VDD), D13.1 (VDD), D14.1 (VDD), D15.1 (VDD), D16.1 (VDD), D17.1 (VDD), D18.1 (VDD), D19.1 (VDD), D20.1 (VDD), D21.1 (VDD), D22.1 (VDD), D23.1 (VDD), D24.1 (VDD), D25.1 (VDD), D26.1 (VDD), D27.1 (VDD), D28.1 (VDD), D29.1 (VDD), D30.1 (VDD), D31.1 (VDD), D32.1 (VDD), D33.1 (VDD), D34.1 (VDD), D35.1 (VDD), D36.1 (VDD), D37.1 (VDD); also elsewhere on the board
GND: C1.1, C2.1, C3.1, C4.1, C5.1, C6.1, C7.1, C8.1, C9.1, C10.1, C11.1, C12.1, C13.1, C14.1, C15.1, C16.1, C17.1, C18.1, C19.1, C20.1, C21.1, C22.1, C23.1, C24.1, C25.1, C26.1, C27.1, C28.1, C29.1, C30.1, C31.1, C32.1, C33.1, C34.1, C35.1, C36.1, D2.3 (VSS), D3.3 (VSS), D4.3 (VSS), D5.3 (VSS), D6.3 (VSS), D7.3 (VSS), D8.3 (VSS), D9.3 (VSS), D10.3 (VSS), D11.3 (VSS), D12.3 (VSS), D13.3 (VSS), D14.3 (VSS), D15.3 (VSS), D16.3 (VSS), D17.3 (VSS), D18.3 (VSS), D19.3 (VSS), D20.3 (VSS), D21.3 (VSS), D22.3 (VSS), D23.3 (VSS), D24.3 (VSS), D25.3 (VSS), D26.3 (VSS), D27.3 (VSS), D28.3 (VSS), D29.3 (VSS), D30.3 (VSS), D31.3 (VSS), D32.3 (VSS), D33.3 (VSS), D34.3 (VSS), D35.3 (VSS), D36.3 (VSS), D37.3 (VSS); also elsewhere on the board
LED Row 2: D7.2 (DOUT), D8.4 (DIN)
LED Row 3: D13.2 (DOUT), D14.4 (DIN)
LED Row 4: D19.2 (DOUT), D20.4 (DIN)
LED Row 5: D25.2 (DOUT), D26.4 (DIN)
LED Row 6: D31.2 (DOUT), D32.4 (DIN)
unnamed: D2.2 (DOUT), D3.4 (DIN)
unnamed: D3.2 (DOUT), D4.4 (DIN)
unnamed: D4.2 (DOUT), D5.4 (DIN)
unnamed: D5.2 (DOUT), D6.4 (DIN)
unnamed: D6.2 (DOUT), D7.4 (DIN)
unnamed: D8.2 (DOUT), D9.4 (DIN)
unnamed: D9.2 (DOUT), D10.4 (DIN)
unnamed: D10.2 (DOUT), D11.4 (DIN)
unnamed: D11.2 (DOUT), D12.4 (DIN)
unnamed: D12.2 (DOUT), D13.4 (DIN)
unnamed: D14.2 (DOUT), D15.4 (DIN)
unnamed: D15.2 (DOUT), D16.4 (DIN)
unnamed: D16.2 (DOUT), D17.4 (DIN)
unnamed: D17.2 (DOUT), D18.4 (DIN)
unnamed: D18.2 (DOUT), D19.4 (DIN)
unnamed: D20.2 (DOUT), D21.4 (DIN)
unnamed: D21.2 (DOUT), D22.4 (DIN)
unnamed: D22.2 (DOUT), D23.4 (DIN)
unnamed: D23.2 (DOUT), D24.4 (DIN)
unnamed: D24.2 (DOUT), D25.4 (DIN)
unnamed: D26.2 (DOUT), D27.4 (DIN)
unnamed: D27.2 (DOUT), D28.4 (DIN)
unnamed: D28.2 (DOUT), D29.4 (DIN)
unnamed: D29.2 (DOUT), D30.4 (DIN)
unnamed: D30.2 (DOUT), D31.4 (DIN)
unnamed: D32.2 (DOUT), D33.4 (DIN)
unnamed: D33.2 (DOUT), D34.4 (DIN)
unnamed: D34.2 (DOUT), D35.4 (DIN)
unnamed: D35.2 (DOUT), D36.4 (DIN)
unnamed: D36.2 (DOUT), D37.4 (DIN)
WS2812 D_in: D2.4 (DIN); also elsewhere on the board

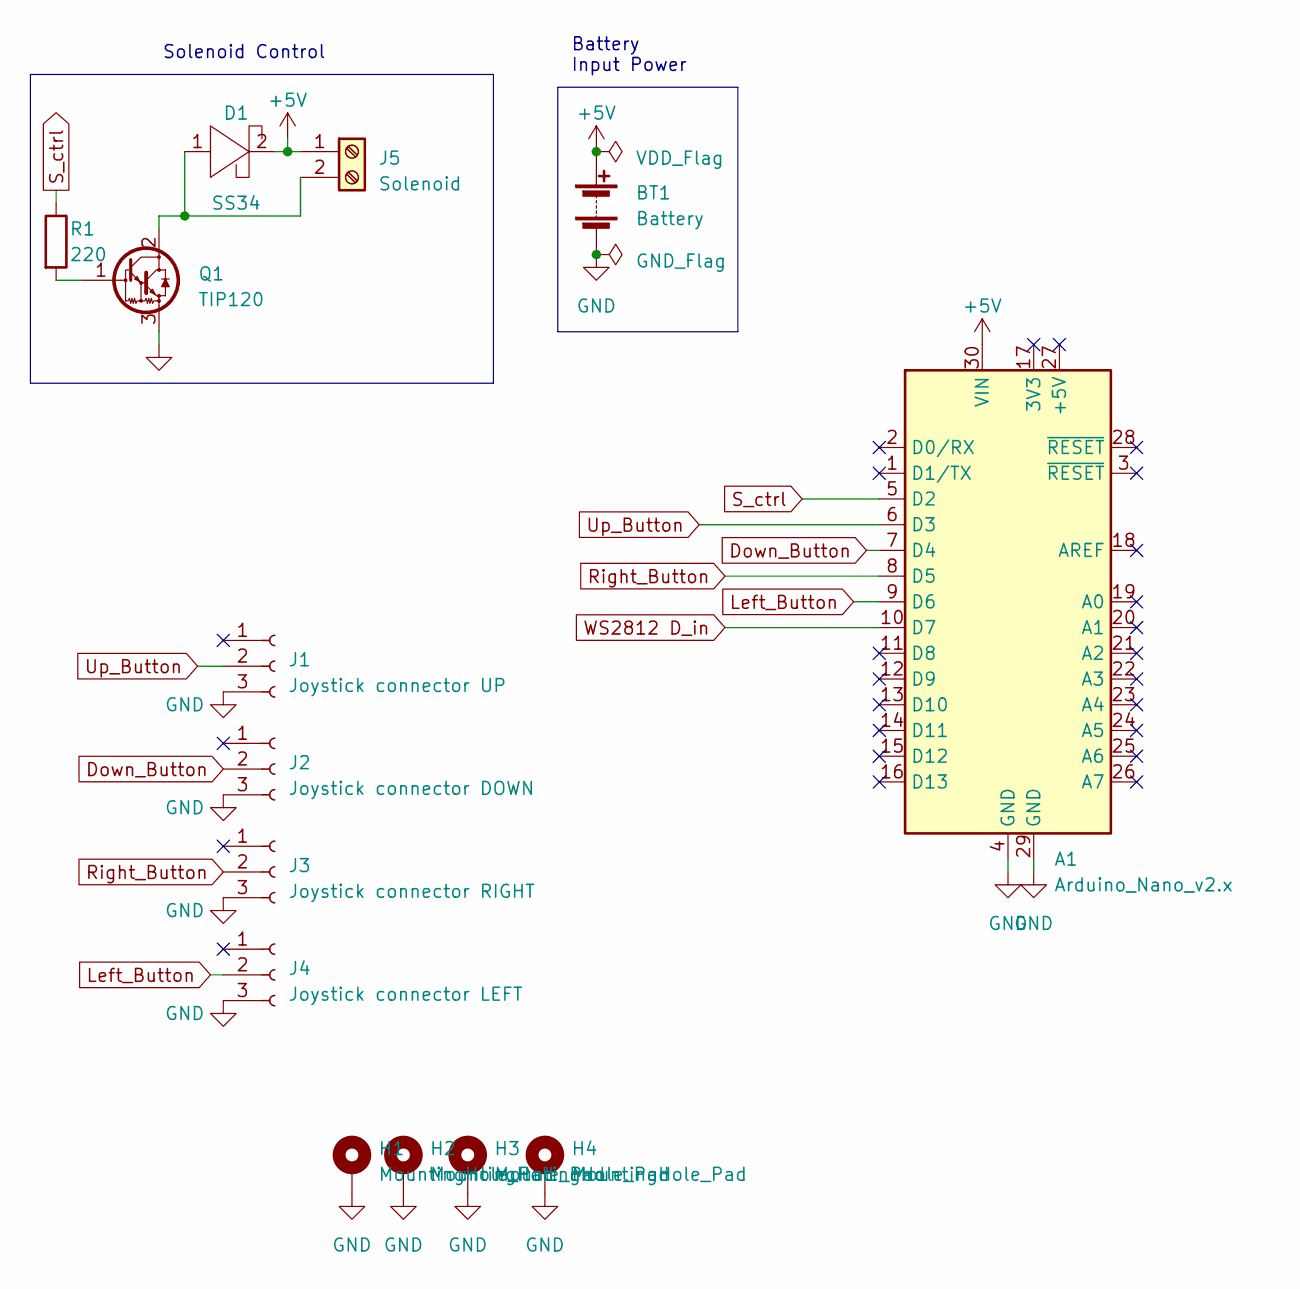
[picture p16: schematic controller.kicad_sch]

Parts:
A1: Arduino_Nano_v2.x; Arduino_Nano
BT1: Battery; BatteryHolder_TruPower_BH-331P_3xAA
D1: SS34
H1, H2, H3, H4: MountingHole_Pad; MountingHole_2.5mm_Pad
J1: Joystick connector UP; JST_PH_B3B-PH-K_1x03_P2.00mm_Vertical
J2: Joystick connector DOWN; JST_PH_B3B-PH-K_1x03_P2.00mm_Vertical
J3: Joystick connector RIGHT; JST_PH_B3B-PH-K_1x03_P2.00mm_Vertical
J4: Joystick connector LEFT; JST_PH_B3B-PH-K_1x03_P2.00mm_Vertical
J5: Solenoid; Altech_AK100_1x02_P5.00mm
Q1: TIP120; TO-220-3_Vertical
R1: 220; R_1206_3216Metric_Pad1.30x1.75mm_HandSolder

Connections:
+5V: A1.30 (VIN), BT1.1 (+), D1.2, J5.1; also elsewhere on the board
Down_Button: A1.7 (D4), J2.2
GND: A1.4 (GND), A1.29 (GND), BT1.2 (-), H1.1, H2.1, H3.1, H4.1, J1.3, J2.3, J3.3, J4.3, Q1.3 (E); also elsewhere on the board
Left_Button: A1.9 (D6), J4.2
unnamed: D1.1, J5.2, Q1.2 (C)
unnamed: Q1.1 (B), R1.2
Right_Button: A1.8 (D5), J3.2
S_ctrl: A1.5 (D2), R1.1
Up_Button: A1.6 (D3), J1.2
WS2812 D_in: A1.10 (D7); also elsewhere on the board

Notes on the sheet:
Solenoid Control
Battery Input Power

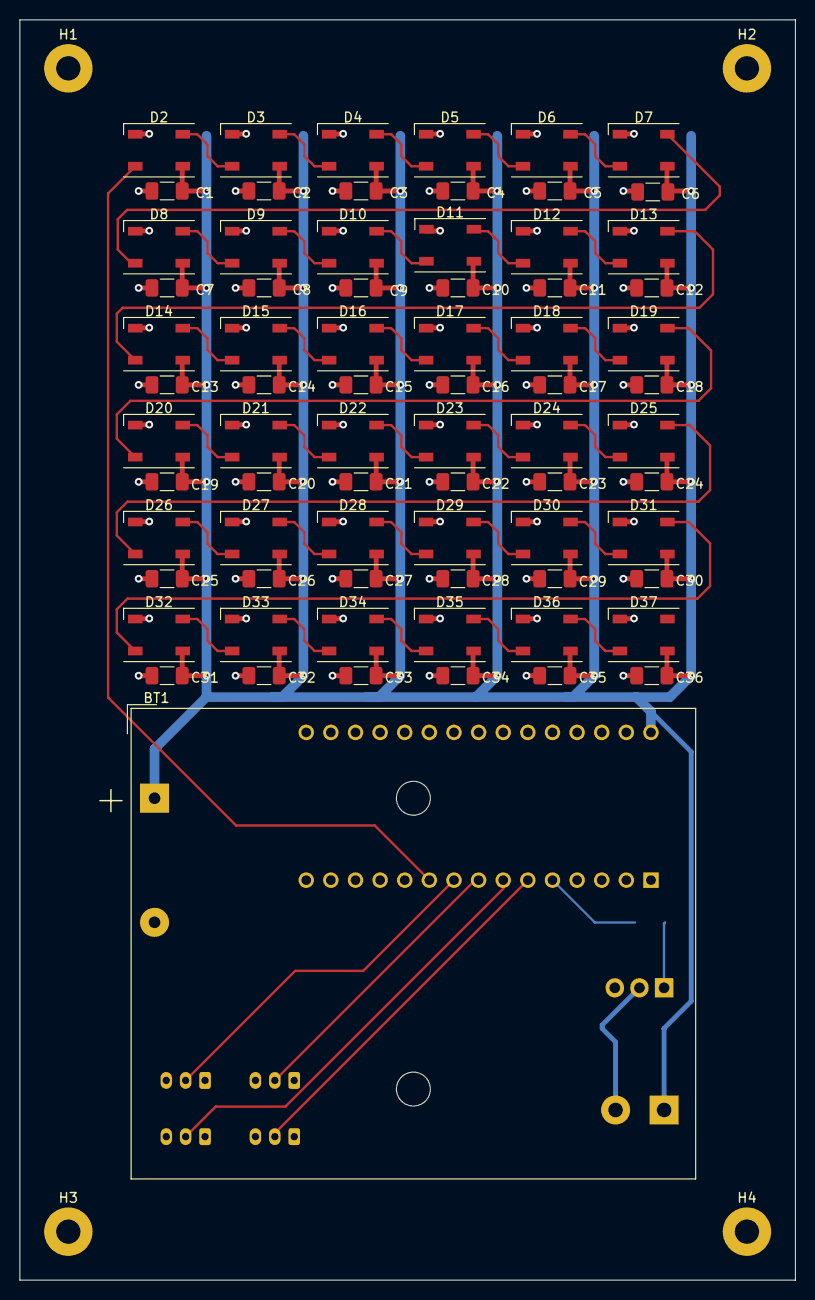
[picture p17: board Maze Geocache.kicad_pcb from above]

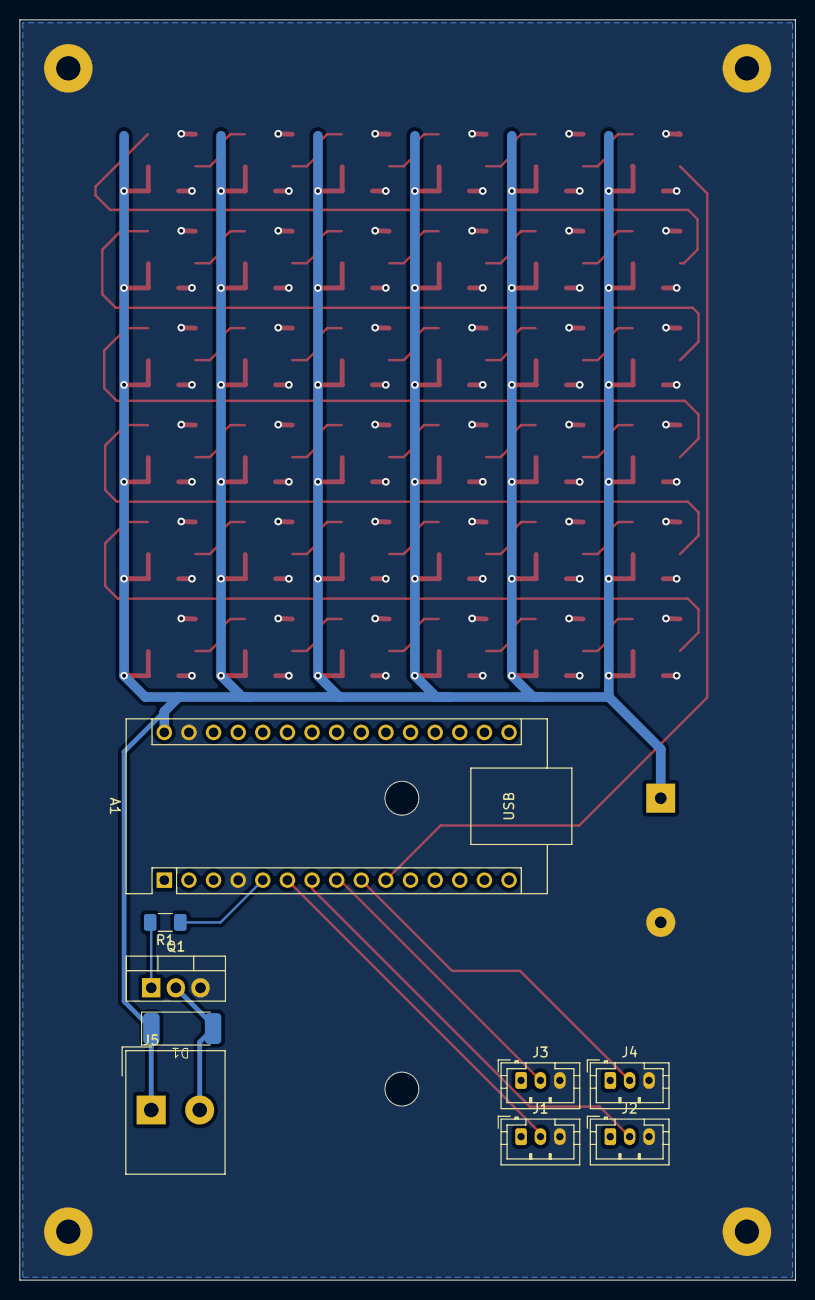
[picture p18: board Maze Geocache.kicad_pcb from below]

Board: 2 copper layers, 80.0 x 130.0 mm, 86 parts (9 on the bottom side), 45 nets.

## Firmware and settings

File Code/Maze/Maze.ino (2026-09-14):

#include <Adafruit_NeoPixel.h>
#include "C:\Users\danda\Documents\Geocaching\Utlegg\Maze Geocahce\MazeWalls.h"

constexpr int MATRIX_PIN = 7;
constexpr int MATRIX_SIZE = 6;
constexpr int NUM_PIXELS = MATRIX_SIZE * MATRIX_SIZE;
constexpr int NUMBER_OF_BUTTONS = 4;
const int relayPin = 2;
const int buttonPins[NUMBER_OF_BUTTONS] = {5, 4, 6, 3}; //RIGHT DOWN LEFT UP
bool lastButtonStates[NUMBER_OF_BUTTONS] = {false, false, false, false};
bool buttonStates[NUMBER_OF_BUTTONS] = {false, false, false, false};
unsigned long lastDebounceTime[NUMBER_OF_BUTTONS] = {0, 0, 0, 0};
int finalPosition;
int currentMaze;
int currentPos;
int numberToGo = 4;
Adafruit_NeoPixel matrix(NUM_PIXELS, MATRIX_PIN, NEO_GRB + NEO_KHZ800);

bool checkButtonPressed(int buttonPin, bool &buttonState, bool &lastButtonState, unsigned long &lastDebounceTime){
  constexpr unsigned long DEBOUNCE_DELAY = 50;
  bool reading = digitalRead(buttonPin) == LOW;
  if (reading != lastButtonState) lastDebounceTime = millis();
  if (millis() - lastDebounceTime > DEBOUNCE_DELAY && reading != buttonState){
    buttonState = reading;
    if (buttonState) return true;
  }
  lastButtonState = reading;
  return false;
}

bool atEdge(int currentPosition, int direction){
  int row = currentPosition / MATRIX_SIZE;
  int column = currentPosition % MATRIX_SIZE;
  if (direction == 1) return column == MATRIX_SIZE - 1;
  if (direction == -1) return column == 0;
  if (direction == MATRIX_SIZE) return row == MATRIX_SIZE - 1;
  if (direction == -MATRIX_SIZE) return row == 0;
  return true;
}

bool hitWall(int currentPosition, int direction, int maze){
  int row = currentPosition / MATRIX_SIZE;
  int column = currentPosition % MATRIX_SIZE;
  if (direction == 1) return wallsVertical[maze][row][column];
  if (direction == -1) return wallsVertical[maze][row][column - 1];
  if (direction == MATRIX_SIZE) return wallsHorizontal[maze][row][column];
  if (direction == -MATRIX_SIZE) return wallsHorizontal[maze][row - 1][column];
  return true;
}

void drawGame(){
  matrix.clear();
  for (int i = 0; i < 2; i++) matrix.setPixelColor(circlePos[currentMaze][i], 0, 50, 0);
  matrix.setPixelColor(finalPosition, 50, 0, 0);
  matrix.setPixelColor(currentPos, 50, 50, 50);
  matrix.show();
}

void blinkRedCross(){
  for (int blinkCount = 0; blinkCount < 3; blinkCount++){
    matrix.clear();
    for (int row = 0; row < MATRIX_SIZE; row++){
      matrix.setPixelColor(row * MATRIX_SIZE + row, 255, 0, 0);
      matrix.setPixelColor(row * MATRIX_SIZE + MATRIX_SIZE - row - 1, 255, 0, 0);
    }
    matrix.show();
    delay(200);
    matrix.clear();
    matrix.show();
    delay(120);
  }
}

void showGreenCheck(int number){
  const int numberOfPixels[] = {12, 8, 11, 11, 12};
  const int zero[] = {2, 3, 7, 10, 13, 16, 19, 22, 25, 28, 32, 33};
  const int one[] = {3, 8, 9, 13, 15, 21, 27, 33};
  const int two[] = {2, 3, 7, 10, 16, 21, 26, 31, 32, 33, 34};
  const int three[] = {2, 3, 7, 10, 15, 16, 22, 25, 28, 32, 33};
  const int four[] = {3, 8, 9, 13, 15, 18, 19, 20, 21, 22, 27, 33};
  matrix.clear();
  for (int i = 0; i < numberOfPixels[number]; i++) {
    int pixel;
    switch (number) {
      case 0:
        pixel = zero[i];
        break;
      case 1:
        pixel = one[i];
        break;
      case 2:
        pixel = two[i];
        break;
      case 3:
        pixel = three[i];
        break;
      case 4:
        pixel = four[i];
        break;
    }
    matrix.setPixelColor(pixel, 0, 255, 0);
  }
  matrix.show();
  delay(1500);
}
void showRedCheck(int number){
  const int numberOfPixels[] = {12, 8, 11, 11,12};
  const int zero[] = {2, 3, 7, 10, 13, 16, 19, 22, 25, 28, 32, 33};
  const int one[] = {3, 8, 9, 13, 15, 21, 27, 33};
  const int two[] = {2, 3, 7, 10, 16, 21, 26, 31, 32, 33, 34};
  const int three[] = {2, 3, 7, 10, 15, 16, 22, 25, 28, 32, 33};
  const int four[] = {3, 8, 9, 13, 15, 18, 19, 20, 21, 22, 27, 33};
  matrix.clear();
  for (int i = 0; i < numberOfPixels[number]; i++) {
    int pixel;
    switch (number) {
      case 0:
        pixel = zero[i];
        break;
      case 1:
        pixel = one[i];
        break;
      case 2:
        pixel = two[i];
        break;
      case 3:
        pixel = three[i];
        break;
      case 4:
        pixel = four[i];
        break;
    }
    matrix.setPixelColor(pixel, 255, 0, 0);
  }
  matrix.show();
  delay(1500);
}
void displayVictorySequence(){
  const int wheelPixels[12] = {2, 3, 10, 17, 23, 28, 33, 32, 25, 18, 12, 7};
  const int standPixels[4] = {26, 27, 31, 34};
  const int cabinColors[4][3] = {
    {255, 0, 0},
    {0, 255, 80},
    {0, 80, 255},
    {255, 100, 0}
  };
  for (int frame = 0; frame < 48; frame++){
    matrix.clear();
    // Wheel outline
    for (int i = 0; i < 12; i++) matrix.setPixelColor(wheelPixels[i], 0, 0, 25);
    // Wheel centre
    matrix.setPixelColor(14, 80, 80, 80);
    matrix.setPixelColor(15, 80, 80, 80);
    matrix.setPixelColor(20, 80, 80, 80);
    matrix.setPixelColor(21, 80, 80, 80);
    // Wheel stand
    for (int i = 0; i < 4; i++) matrix.setPixelColor(standPixels[i], 80, 40, 0);
    // Four rotating cabins
    for (int cabin = 0; cabin < 4; cabin++){
      int wheelIndex = (frame + cabin * 3) % 12;
      int pixel = wheelPixels[wheelIndex];
      matrix.setPixelColor(pixel, cabinColors[cabin][0], cabinColors[cabin][1], cabinColors[cabin][2]);
    }
    matrix.show();
    delay(80);
  }
  matrix.clear();
  matrix.show();
}

int getPosition(int notSameAs = -1){
  int position = random(NUM_PIXELS);
  while (position == notSameAs) position = random(NUM_PIXELS);
  return position;
}

int getMazePosition(int notSameAs = -1){
  int position = getPosition(notSameAs);
  while (position == circlePos[currentMaze][0] || position == circlePos[currentMaze][1]) position = getPosition(notSameAs);
  return position;
}
void moveLight(int direction){
  if (atEdge(currentPos, direction)){
    Serial.println("You hit the edge");
    blinkRedCross();
    numberToGo = 4;
    showRedCheck(numberToGo);
    currentMaze = random(MAZE_COUNT);
    currentPos = getMazePosition();
    finalPosition = getMazePosition(currentPos);
    drawGame();
    return;
  }
  else if (hitWall(currentPos, direction, currentMaze)){
    Serial.println("You hit a wall");
    blinkRedCross();
    numberToGo = 4;
    showRedCheck(numberToGo);
    currentMaze = random(MAZE_COUNT);
    currentPos = getMazePosition();
    finalPosition = getMazePosition(currentPos);
    drawGame();
    return;
  }
  matrix.setPixelColor(currentPos, 0, 0, 0);
  if (currentPos == circlePos[currentMaze][0] || currentPos == circlePos[currentMaze][1]) matrix.setPixelColor(currentPos, 0, 50, 0);
  currentPos += direction;
  matrix.setPixelColor(currentPos, 50, 50, 50);
}



void setup(){
  matrix.begin();
  matrix.setBrightness(255);
  matrix.clear();
  matrix.show();
  pinMode(relayPin, OUTPUT);
  digitalWrite(relayPin, LOW);
  for (int i = 0; i < NUMBER_OF_BUTTONS; i++) pinMode(buttonPins[i], INPUT_PULLUP);
  randomSeed(analogRead(0));
  currentMaze = random(MAZE_COUNT);
  currentPos = getMazePosition();
  finalPosition = getMazePosition(currentPos);
  Serial.begin(9600);
  Serial.println(__FILE__);
  Serial.println("Comiled: "  __DATE__ ", " __TIME__);
  Serial.println("Starting:");
  //displayVictorySequence();
  /*
  for (int i = 0; i < NUM_PIXELS; i++){
    if (i) matrix.setPixelColor(i-1, 0, 0, 0);
    matrix.setPixelColor(i, 50, 50, 50);
    matrix.show();
    delay(50);
  }
  matrix.clear();
  */
  Serial.print("Current Maze: ");
  Serial.println(currentMaze);
  Serial.print("Final Position: ");
  Serial.println(finalPosition);
  drawGame();
}

void loop(){
  for (int i = 0; i < NUMBER_OF_BUTTONS; i++){
    if (checkButtonPressed(buttonPins[i], buttonStates[i], lastButtonStates[i], lastDebounceTime[i])){
      if (i == 0){
        moveLight(1);
        Serial.println("Moving Right");
      }
      else if (i == 1){
        moveLight(MATRIX_SIZE);
        Serial.println("Moving Down");
      }
      else if (i == 2){
        moveLight(-1);
        Serial.println("Moving Left");
      }
      else{
        moveLight(-MATRIX_SIZE);
        Serial.println("Moving Up");
      }
      matrix.show();
    }
  }
  if (currentPos == finalPosition){
    Serial.println("You found the final position");
    numberToGo--;
    if (numberToGo <= 0){
      displayVictorySequence();
      digitalWrite(relayPin, HIGH);
      delay(500);
      digitalWrite(relayPin, LOW);
      numberToGo = 4;
      currentMaze = random(MAZE_COUNT);
      currentPos = getMazePosition();
      finalPosition = getMazePosition(currentPos);
      drawGame();
    }
    else{
      Serial.print("You have ");
      Serial.print(numberToGo);
      Serial.println(" more to go");
      showGreenCheck(numberToGo);
      currentMaze = random(MAZE_COUNT);
      currentPos = getMazePosition();
      finalPosition = getMazePosition(currentPos);
      drawGame();
    }
    
  }
}

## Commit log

2024-03-19 Refactor Arduino code for "Keep Talking and Nobody Explodes" geocache
2026-09-14 Complete Project
    [Acryl glass.dxf, Box ready.dxf, Maze Geocache Fusion Archive.f3d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]
2026-09-15 6mm design
    [Acrylic 6mm.dxf, Box complete 6mm.dxf, Complete box with content 6mm.step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]
